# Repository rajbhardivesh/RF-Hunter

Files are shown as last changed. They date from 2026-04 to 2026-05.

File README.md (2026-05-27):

# RF Hunter — Wireless Security Research Platform

**ESP8266 + nRF24L01 · OLED Display · Open Source Hardware & Firmware**


[]()
[]()

> A compact, standalone wireless security research device. Three tools in one — RF jammer, Wi-Fi deauther, and captive portal testbed — controlled from a 128×64 OLED display and 6-button keypad. No laptop required.

---

## Buy a pre-built unit

If you want to skip the build and get straight to learning:

**[→ Buy RF-Hunter at rdhrobotics.in](https://rdhrobotics.in/products/rf-hunter)**

Assembled, tested, and shipped. Includes quick-start card.

---

## What it does

The RF-Hunter is a hardware platform for studying 2.4 GHz wireless security concepts hands-on. It runs three independent research modules from a unified launcher UI:

| Module | Description |
|---|---|
| **RF-Hunter** | Sweeps all 125 nRF24 channels or Wi-Fi bands only. Studies RF interference in the 2.4 GHz space. |
| **Deauther Suite** | spacehuhn deauther engine. Scan APs, study 802.11 management frame behaviour. |
| **WiPhi** | Evil twin AP + captive portal testbed. Study how credential phishing portals work. |
| **RF Chat** | *(bonus sketch)* Point-to-point text chat over raw nRF24 radio. |

Everything is navigated from the OLED + keypad, or remotely via the built-in web admin panel at `192.168.4.1`.

---

## Hardware

| Component | Part |
|---|---|
| MCU | ESP8266 (80/160 MHz, 2.4 GHz Wi-Fi) |
| RF module | nRF24L01+ PA+LNA |
| Display | SH1106 128×64 OLED (I²C) |
| Input | 6-button ADC keypad (voltage divider) |
| Storage | EEPROM — 5-slot credential vault, persists across reboots |

### Pinout

```raw
nRF24L01   CE  → GPIO16
           CSN → GPIO15

SH1106     SDA → GPIO4
           SCL → GPIO5
```

### ADC button thresholds

```cpp
#define BTN_UP     135
#define BTN_DOWN   579
#define BTN_LEFT   426
#define BTN_RIGHT  634
#define BTN_ENTER  729
#define BTN_BACK   687
```

Adjust values to match your resistor network.

---

## Firmware

### Requirements

- Arduino IDE 1.8+ or PlatformIO
- ESP8266 board package
- Libraries: `RF24`, `ESP8266WiFi`, `DNSServer`, `ESP8266WebServer`, `SH1106Wire` (ESP8266-OLED), `ADCButton`, `ArduinoJson v5`

### Install

```bash
git clone https://github.com/rdhrobotics/RF-Hunter.git
```

Open `RFHunter/RFHunter.ino` in Arduino IDE. Select **Generic ESP8266 (Deauther)** as the board. Flash at 115200 baud.

### Repository structure

```raw
RF-Hunter/
├── RFHunter/
│   └── RFHunter.ino        ← main sketch (all three tools)
│
├── Hardware Source/
│   ├── RD_Deauther.pdf // schematic
│   └── RD_Deauther.kicad_pro // Kicad Project

```

---

## UI overview

```raw
┌─────────────────┐
│     Main Menu   │  ← Launcher
│  > RF-Hunter    │
│    Deauther     │
│    WiPhi        │
└─────────────────┘
        │
        ├── RF-Hunter → select mode → running (BACK to stop)
        ├── Deauther  → full spacehuhn DisplayUI
        └── WiPhi     → scan → select AP → attack → captured PW
```

Hold **BACK for 5 seconds** from any mode to return to the launcher main menu.

---

## Adding a new RF mode (3 steps)

The launcher uses a mode table — drop in a new attack without touching the state machine.

**Step 1** — declare your functions:
```cpp
void myMode_init();
void myMode_tick();
```

**Step 2** — add a row to the table:
```cpp
const NrfMode NRF_MODES[] = {
    { "BLE & All 2.4GHz", nrfAttackAllInit,  nrfAttackAllTick,  true },
    { "Just Wi-Fi",       nrfAttackWiFiInit, nrfAttackWiFiTick, true },
    { "My New Mode",      myMode_init,       myMode_tick,       false }, // ← add here
};
```

**Step 3** — write the functions anywhere below. Done.

---

## EEPROM layout

WiPhi saves captured credentials to EEPROM and survives power cycles.

```raw
Addr 0        Magic byte (0xAB) — detects first boot
Addr 1–485    5 slots × (1 valid flag + 32 SSID + 64 PW)

WiPhi vault (in Launcher, offset to avoid deauther collision):
Addr 2000     Magic byte (0xBC)
Addr 2001+    Same slot layout × 5
```

Browse and delete saved passwords from the OLED: **Main Menu → Saved Passwords**.

---

## Web admin panel

While WiPhi is running, connect to:

```raw
SSID:     WiPhi_34732
Password: d347h320
URL:      http://192.168.4.1/admin
```

The web UI and OLED run simultaneously — control from either.

---

## Open source

This project is fully open source — firmware and hardware both.

| | License |
|---|---|
| Firmware | [MIT](LICENSE) |
| Hardware (schematic, BOM) | [CERN OHL v2 Permissive](LICENSE-HW) |

The Deauther Suite module uses the [spacehuhn/esp8266_deauther](https://github.com/SpacehuhnTech/esp8266_deauther) engine, which is also MIT licensed.

Pull requests welcome. See [CONTRIBUTING.md](CONTRIBUTING.md) for guidelines.

---

## Ethical use

This device is built for **authorized security research, CTF competitions, and educational use**.

- Only use on networks and devices you own or have explicit written permission to test
- Unauthorized deauthentication, RF jamming, or credential harvesting is illegal in most jurisdictions
- The authors take no responsibility for misuse

---

## Made with ❤️

by [@rdhrobotics](https://rdhrobotics.in) — open hardware for security education.

**[→ Buy pre-built at rdhrobotics.in](https://rdhrobotics.in/products/rf-hunter)**

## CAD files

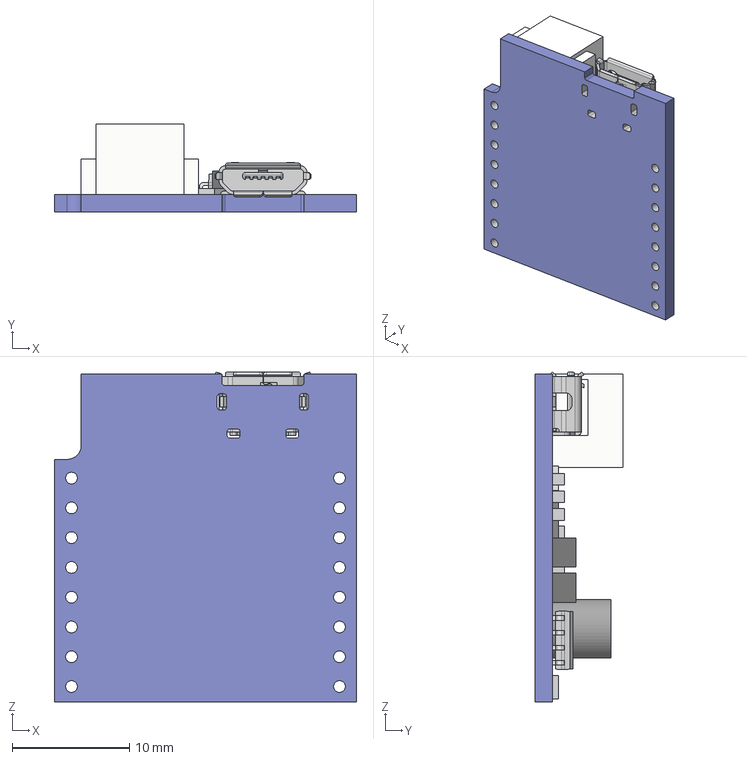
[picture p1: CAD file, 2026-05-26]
Hardware Source/3D/D1_mini_LiPo_Shield.step
25.8 x 7.50 x 28.2 mm

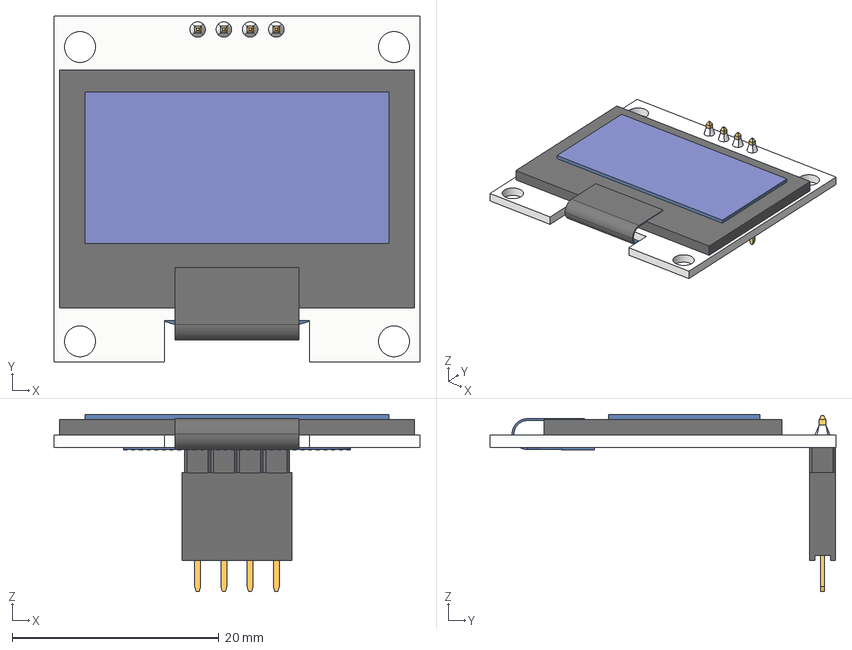
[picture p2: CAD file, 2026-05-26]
Hardware Source/3D/OLED.step
35.4 x 33.5 x 17.1 mm
Board
PIN HEADER MALE 2.54MM P4
LCD
FLEX FILM
4 lü Lehim
PIN HEADER FAMALE 2.54MM P4

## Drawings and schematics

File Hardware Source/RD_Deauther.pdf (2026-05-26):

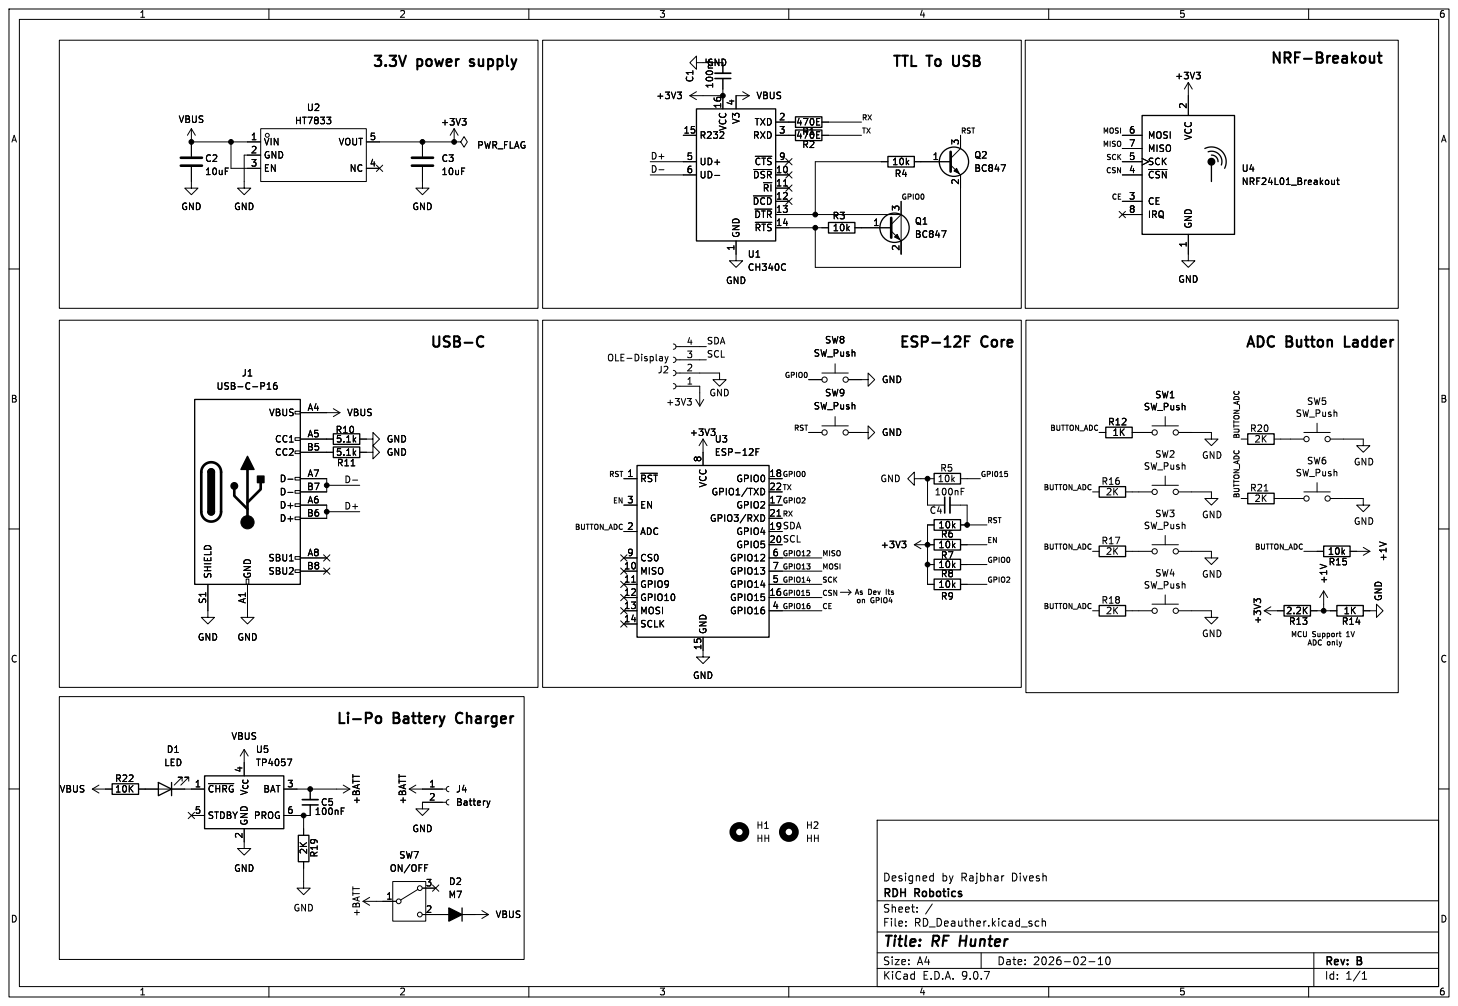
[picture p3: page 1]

1 TXD 2 RXD 3 ~{CTS}9 ~{DSR} 10 ~{RI} 11 ~{DCD} 12 ~{DTR} 13 ~{RTS} 14 U1 CH340C C1 100nF SW2 SW_Push +1V R13

1 TXD 2 RXD 3 ~{CTS}9 ~{DSR} 10 ~{RI} 11 ~{DCD} 12 ~{DTR} 13 ~{RTS} 14 C1 100nF

8 GND 15 GPIO0 18 GPIO1/TXD 22 GPIO2 17 GPIO3/RXD 21 GPIO4 19 GPIO5 20 GPIO12 6 GPIO13 7 GPIO14 5 GPIO15 16 GPIO16 4 GND GND

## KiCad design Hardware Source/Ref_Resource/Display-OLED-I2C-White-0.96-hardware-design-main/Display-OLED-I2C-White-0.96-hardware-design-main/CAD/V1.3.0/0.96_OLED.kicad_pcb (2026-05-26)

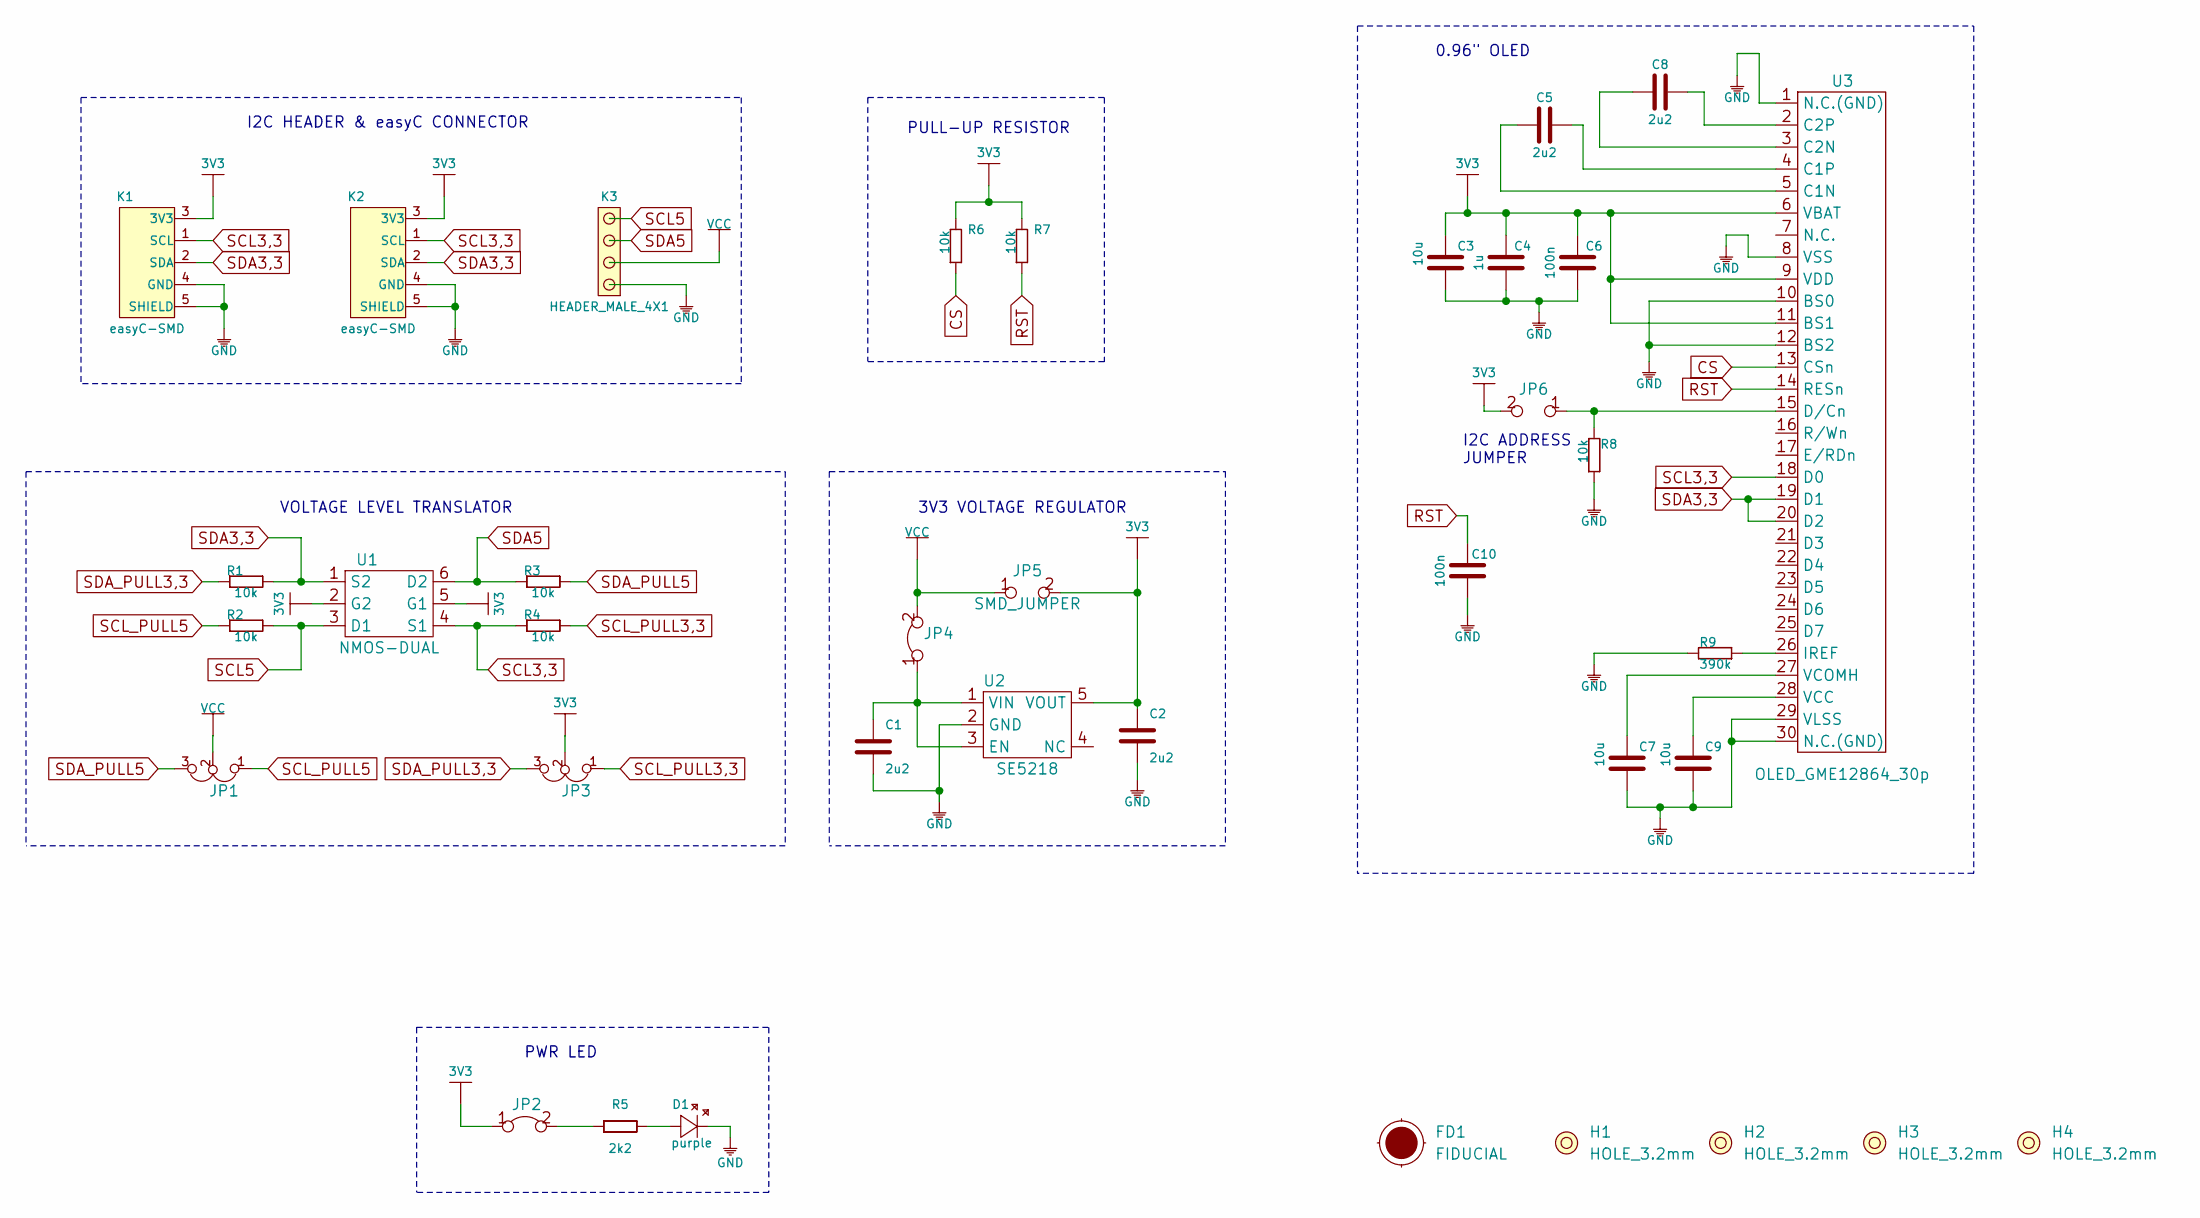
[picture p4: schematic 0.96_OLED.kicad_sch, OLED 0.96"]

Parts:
C1, C2, C5, C8: 2u2; 0603C
C3, C7, C9: 10u; 1206C
C4: 1u; 0603C
C6, C10: 100n; 0603C
D1: purple; 0402LED
FD1: FIDUCIAL; FIDUCIAL_23
H1, H2, H3, H4: HOLE_3.2mm
JP1, JP3: SMD_JUMPER_3_PAD_TRACE
JP2, JP4: SMD-JUMPER-CONNECTED_TRACE_SLODERMASK
JP5, JP6: SMD_JUMPER
K1, K2: easyC-SMD; easyC-connector
K3: HEADER_MALE_4X1
R1, R2, R3, R4, R6, R7, R8: 10k; 0603R
R5: 2k2; 0402R
R9: 390k; 0603R
U1: NMOS-DUAL; SOT-363
U2: SE5218; SOT-23-5
U3: OLED_GME12864_30p; OLED_GME128x64_30p

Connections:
3V3: C2.2, C3.1, C4.1, C6.1, JP2.1, JP3.2, JP5.2, JP6.2, K1.3 (3V3), K2.3 (3V3), R6.2, R7.2, U1.2 (G2), U1.5 (G1), U2.5 (VOUT), U3.6 (VBAT), U3.9 (VDD), U3.11 (BS1)
CS: R6.1, U3.13 (CSn)
GND: C1.1, C2.1, C3.2, C4.2, C6.2, C7.2, C9.2, C10.2, D1.2 (K), K1.4 (GND), K1.5 (SHIELD), K2.4 (GND), K2.5 (SHIELD), K3.1, R8.1, R9.2, U2.2 (GND), U3.1 (N.C.(GND)), U3.8 (VSS), U3.10 (BS0), U3.12 (BS2), U3.29 (VLSS), U3.30 (N.C.(GND))
unnamed: C1.2, JP4.1, U2.1 (VIN), U2.3 (EN)
unnamed: C5.1, U3.5 (C1N)
unnamed: C5.2, U3.4 (C1P)
unnamed: C7.1, U3.27 (VCOMH)
unnamed: C8.1, U3.3 (C2N)
unnamed: C8.2, U3.2 (C2P)
unnamed: C9.1, U3.28 (VCC)
unnamed: D1.1 (A), R5.2
unnamed: JP2.2, R5.1
unnamed: JP6.1, R8.2, U3.15 (D/Cn)
unnamed: R9.1, U3.26 (IREF)
RST: C10.1, R7.1, U3.14 (RESn)
SCL3,3: K1.1 (SCL), K2.1 (SCL), R4.1, U1.4 (S1), U3.18 (D0)
SCL5: K3.4, R2.2, U1.3 (D1)
SCL_PULL3,3: JP3.1, R4.2
SCL_PULL5: JP1.1, R2.1
SDA3,3: K1.2 (SDA), K2.2 (SDA), R1.2, U1.1 (S2), U3.19 (D1), U3.20 (D2)
SDA5: K3.3, R3.1, U1.6 (D2)
SDA_PULL3,3: JP3.3, R1.1
SDA_PULL5: JP1.3, R3.2
VCC: JP1.2, JP4.2, JP5.1, K3.2

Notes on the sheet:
0.96" OLED
3V3 VOLTAGE REGULATOR
I2C ADDRESS JUMPER
I2C HEADER & easyC CONNECTOR
PULL-UP RESISTOR
VOLTAGE LEVEL TRANSLATOR
PWR LED

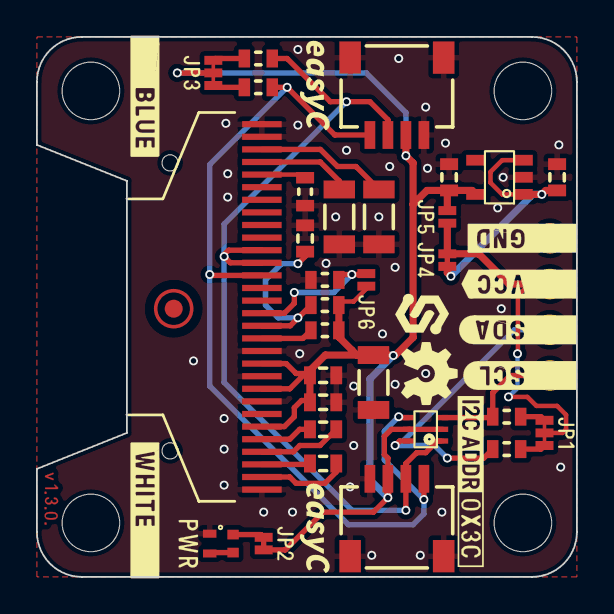
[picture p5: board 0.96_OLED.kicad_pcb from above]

Board: 2 copper layers, 30.0 x 30.0 mm, 37 parts (0 on the bottom side), 24 nets.

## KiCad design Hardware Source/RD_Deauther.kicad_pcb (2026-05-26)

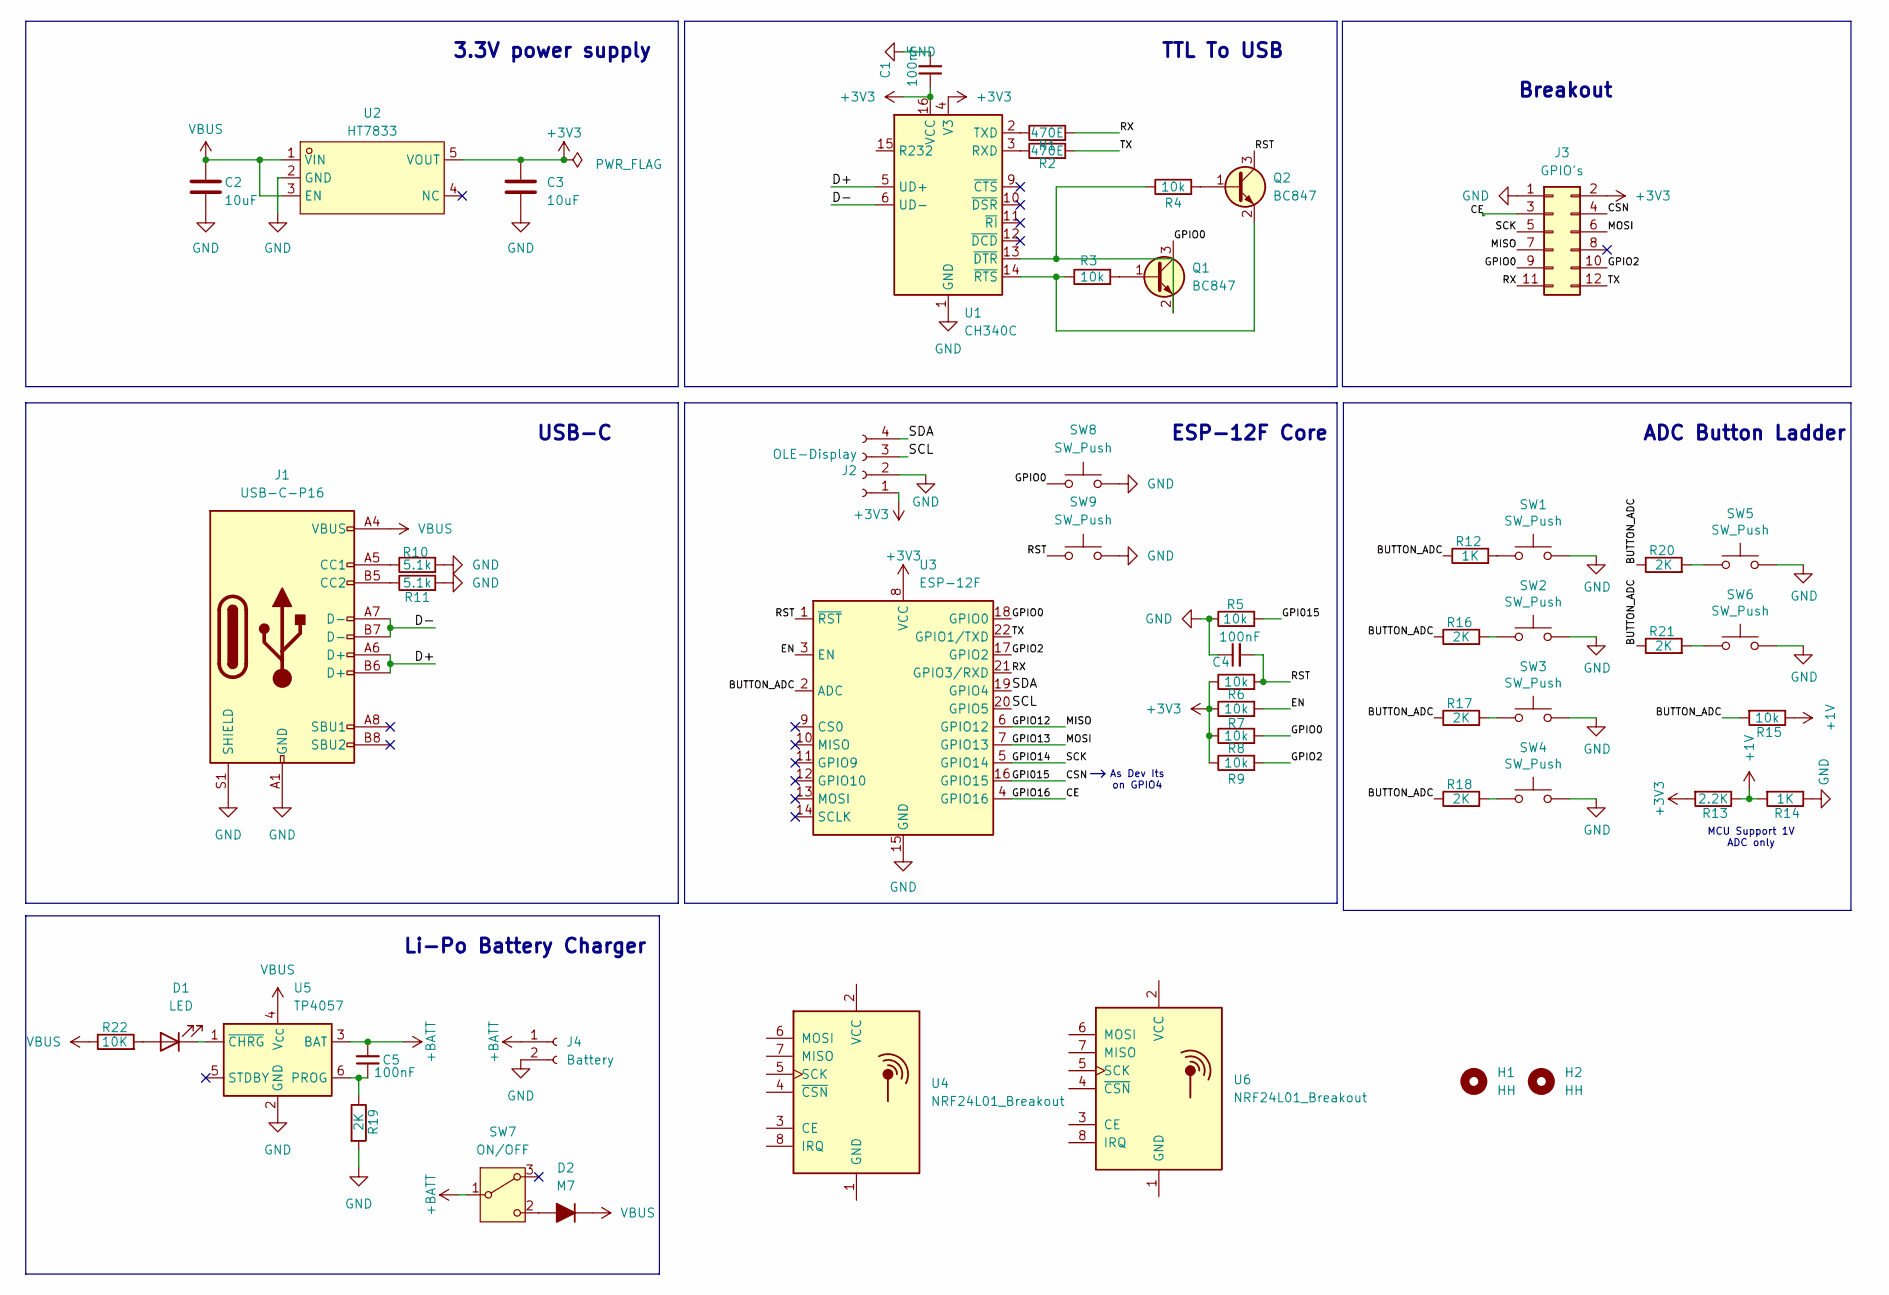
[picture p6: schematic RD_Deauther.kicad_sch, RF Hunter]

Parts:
C1, C4, C5: 100nF; C_1206_3216Metric_Pad1.33x1.80mm_HandSolder
C2, C3: 10uF; C_1206_3216Metric_Pad1.33x1.80mm_HandSolder
D1: LED; LED_1206_3216Metric_Pad1.42x1.75mm_HandSolder
D2: M7; D_SMA
H1, H2: HH; MountingHole_3.2mm_M3
J1: USB-C-P16; USB_C_Receptacle_GCT_USB4105-xx-A_16P_TopMnt_Horizontal
J2: OLE-Display; OLED-1.3Inch
J3: GPIO's; PinSocket_2x06_P2.54mm_Vertical
J4: Battery; JST_PH_B2B-PH-K_1x02_P2.00mm_Vertical
Q1, Q2: BC847; SOT-23
R1, R2: 470E; R_1206_3216Metric_Pad1.30x1.75mm
R3, R4, R5, R6, R7, R8, R9, R15: 10k; R_1206_3216Metric_Pad1.30x1.75mm
R10, R11: 5.1k; R_1206_3216Metric_Pad1.30x1.75mm
R12, R14: 1K; R_1206_3216Metric_Pad1.30x1.75mm
R13: 2.2K; R_1206_3216Metric_Pad1.30x1.75mm
R16, R17, R18, R19, R20, R21: 2K; R_1206_3216Metric_Pad1.30x1.75mm
R22: 10K; R_1206_3216Metric_Pad1.30x1.75mm
SW1, SW2, SW3, SW4, SW5, SW6: SW_Push; SW_Push_1P1T_NO_E-Switch_TL3301NxxxxxG
SW7: ON/OFF; SW_SPDT_PCM12
SW8, SW9: SW_Push; SW_SPST_TL3342
U1: CH340C; SOIC-16_3.9x9.9mm_P1.27mm
U2: HT7833; SOT-23-5; MPN C82942
U3: ESP-12F; ESP-12E
U4, U6: NRF24L01_Breakout; nRF24L01_Breakout
U5: TP4057; TSOT-23-6

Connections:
+1V: R13.1, R14.2, R15.1
+3V3: C1.1, C3.1, J2.1, J3.2, R6.1, R7.1, R8.1, R9.1, R13.2, U1.4 (V3), U1.16 (VCC), U2.5 (VOUT), U3.8 (VCC)
+BATT: C5.2, J4.1, SW7.1 (B), U5.3 (BAT)
/BUTTON_ADC: R12.1, R15.2, R16.1, R17.1, R18.1, R20.1, R21.1, U3.2 (ADC)
/CE: J3.3, U3.4 (GPIO16)
/CSN: J3.4, R5.2, U3.16 (GPIO15)
/D+: J1.A6 (D+), J1.B6 (D+), U1.5 (UD+)
/D-: J1.A7 (D-), J1.B7 (D-), U1.6 (UD-)
/EN: R7.2, U3.3 (EN)
/GPIO0: J3.9, Q1.3 (C), R8.2, SW8.1, U3.18 (GPIO0)
/GPIO2: J3.10, R9.2, U3.17 (GPIO2)
/GPIO12: J3.7, U3.6 (GPIO12)
/GPIO13: J3.6, U3.7 (GPIO13)
/GPIO14: J3.5, U3.5 (GPIO14)
/RST: C4.2, Q2.3 (C), R6.2, SW9.1, U3.1 (~RST)
/RX: J3.11, R1.2, U3.21 (GPIO3/RXD)
/SCL: J2.3, U3.20 (GPIO5)
/SDA: J2.4, U3.19 (GPIO4)
/TX: J3.12, R2.2, U3.22 (GPIO1/TXD)
GND: C1.2, C2.1, C3.2, C4.1, J1.A1 (GND), J1.A12 (GND), J1.B1 (GND), J1.B12 (GND), J1.S1 (SHIELD), J2.2, J3.1, J4.2, R5.1, R10.2, R11.2, R14.1, R19.2, SW1.2, SW2.2, SW3.2, SW4.2, SW5.2, SW6.2, SW8.2, SW9.2, U1.1 (GND), U2.2 (GND), U3.15 (GND), U5.2 (GND)
unnamed: D1.2 (A), R22.2
unnamed: D1.1 (K), U5.1 (~CHRG)
unnamed: D2.2 (A), SW7.2 (C)
unnamed: J1.A5 (CC1), R10.1
unnamed: J1.B5 (CC2), R11.1
unnamed: Q1.1 (B), R3.2
unnamed: Q1.2 (E), R4.1, U1.13 (~DTR)
unnamed: Q2.1 (B), R4.2
unnamed: Q2.2 (E), R3.1, U1.14 (~RTS)
unnamed: R12.2, SW1.1
unnamed: R16.2, SW2.1
unnamed: R17.2, SW3.1
unnamed: R18.2, SW4.1
unnamed: R20.2, SW5.1
unnamed: R21.2, SW6.1
unnamed: R2.1, U1.3 (RXD)
unnamed: R1.1, U1.2 (TXD)
unnamed: C5.1, R19.1, U5.6 (PROG)
VBUS: C2.2, D2.1 (K), J1.A4 (VBUS), J1.A9 (VBUS), J1.B4 (VBUS), J1.B9 (VBUS), R22.1, U2.1 (VIN), U2.3 (EN), U5.4 (V_{CC})

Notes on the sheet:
As Dev Its on GPIO4
MCU Support 1V ADC only
USB-C
Breakout
TTL To USB
Li-Po Battery Charger
3.3V power supply
ESP-12F Core
ADC Button Ladder

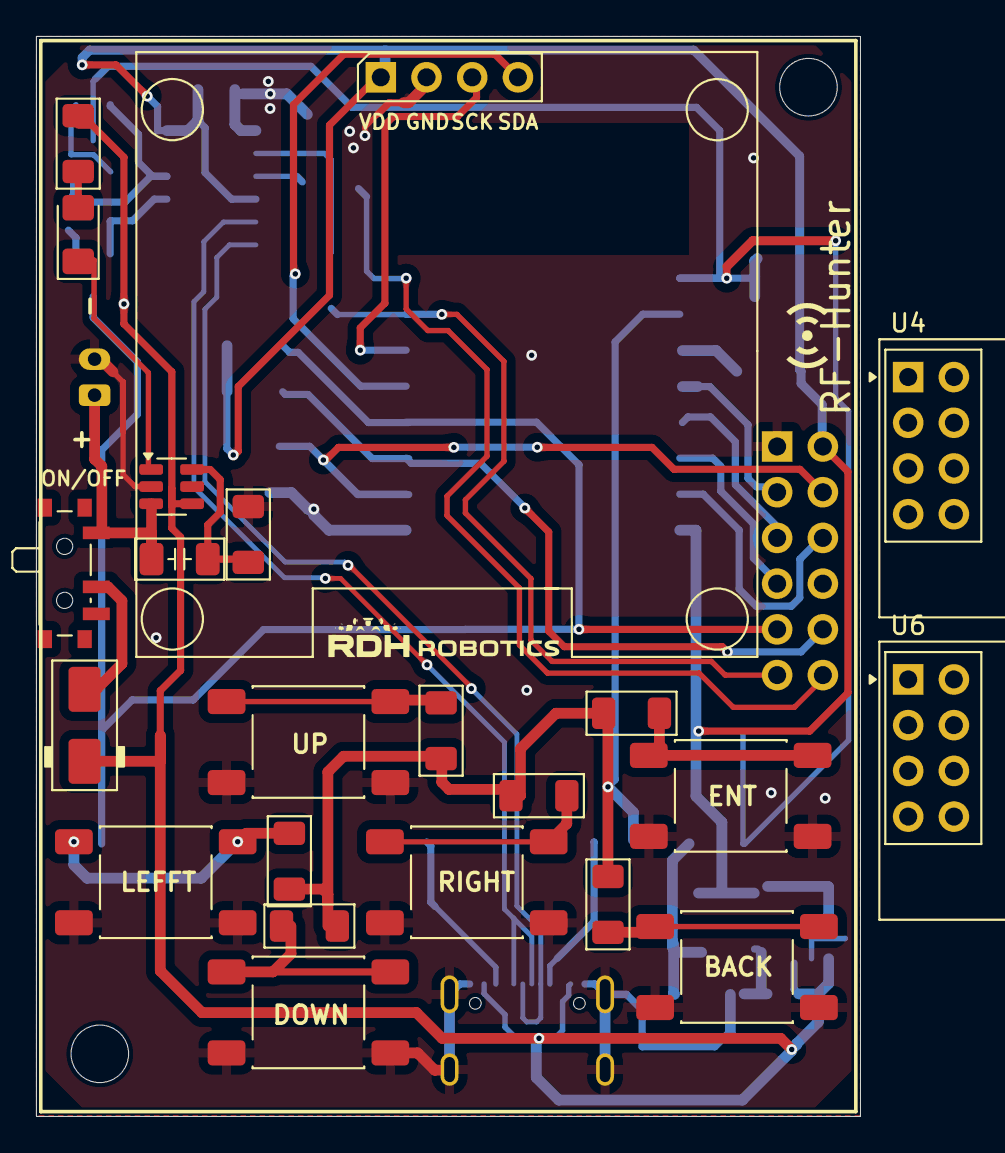
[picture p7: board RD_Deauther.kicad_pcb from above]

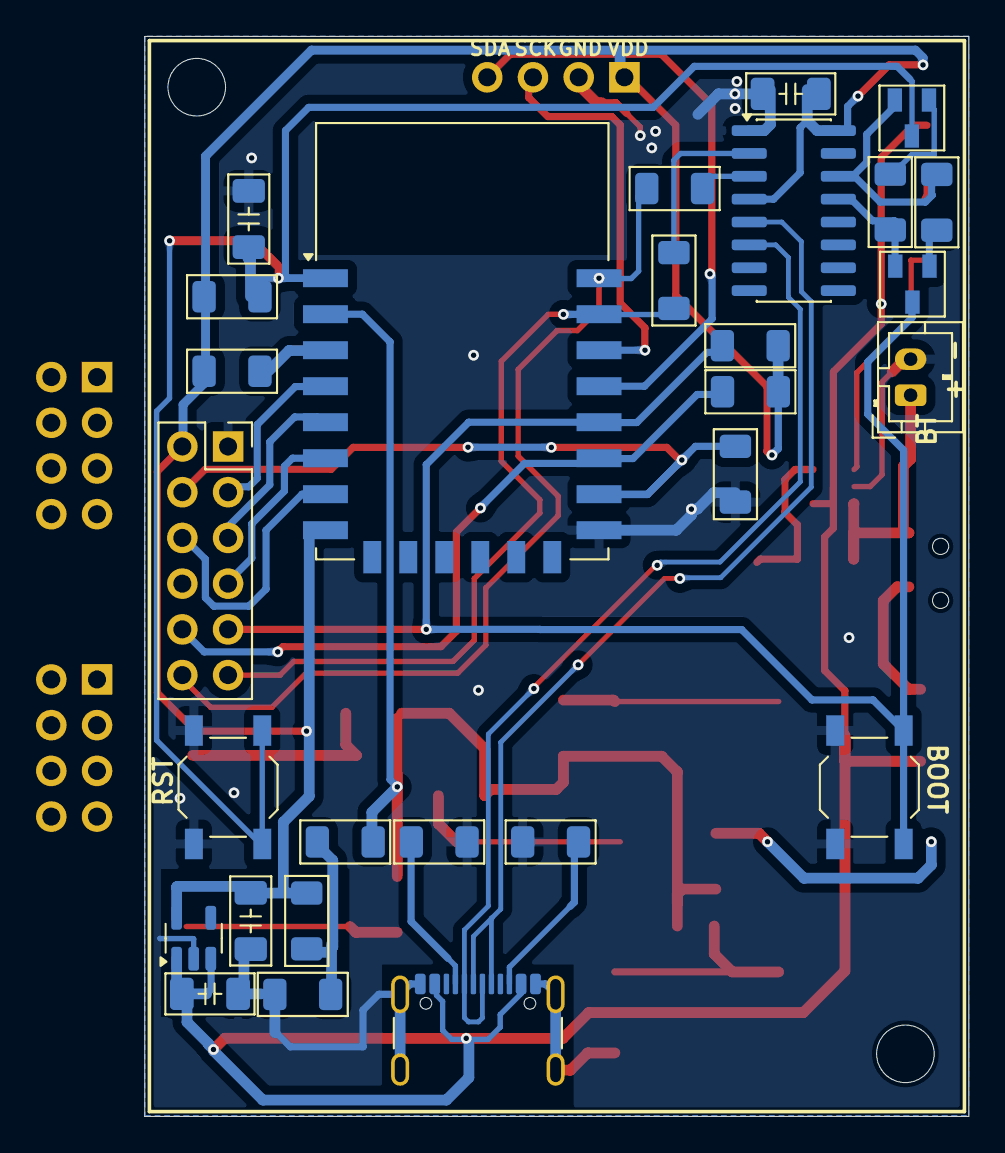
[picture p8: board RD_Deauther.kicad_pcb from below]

Board: 2 copper layers, 45.8 x 60.0 mm, 52 parts (28 on the bottom side), 39 nets.

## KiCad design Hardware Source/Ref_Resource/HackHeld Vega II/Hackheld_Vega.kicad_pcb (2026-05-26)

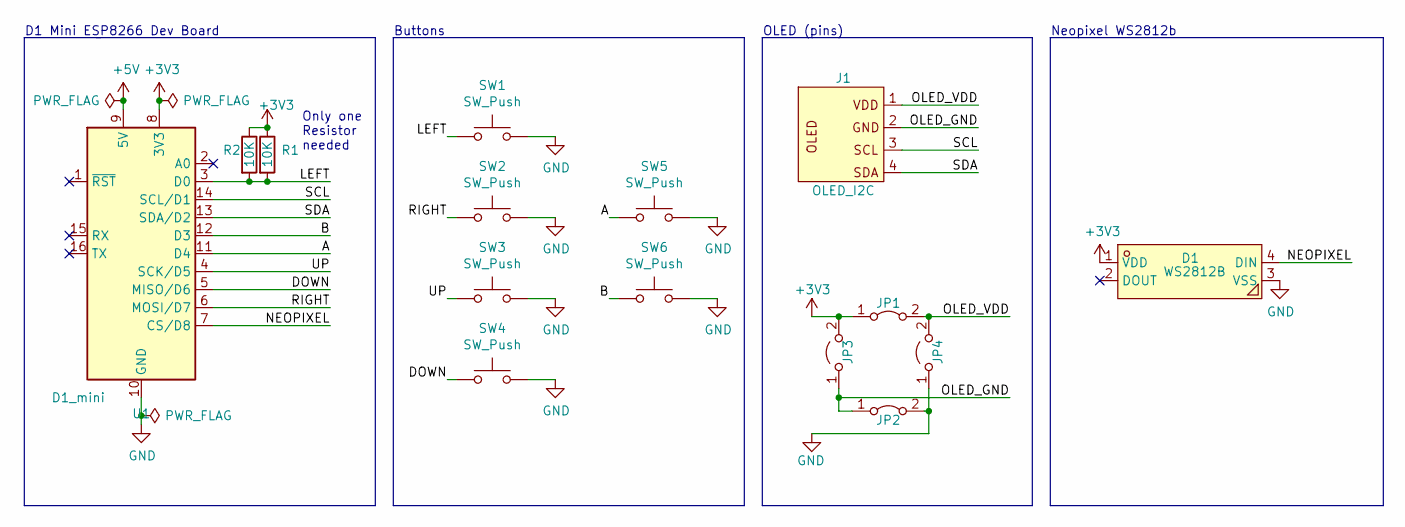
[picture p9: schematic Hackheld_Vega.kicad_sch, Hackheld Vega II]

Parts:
D1: WS2812B; LED-SMD_4P-L5.0-W5.0-BL_TC5050RGB-handsolder; MPN C114586
J1: OLED_I2C; OLED_I2C_1.3
JP1, JP2: Jumper_2_Bridged; Bridge
JP3, JP4: Jumper_2_Open; SolderJumper_Open
R1: 10K; R_1206_3216Metric_Pad1.30x1.75mm_HandSolder
R2: 10K; R_Axial_DIN0204_L3.6mm_D1.6mm_P7.62mm_Horizontal
SW1, SW2, SW3, SW4, SW6: SW_Push; SW-KEY-TH_4P-L6.0-W6.0-P4.50-LS6.5; MPN C381013; LCSC Part C381013
SW5: SW_Push; SW-KEY-TH_4P-L6.0-W6.0-P4.50-LS6.5; MPN C381013
U1: D1_mini; D1_mini_ESP8266

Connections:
+3V3: D1.1 (VDD), JP1.1 (A), JP3.2 (B), R1.1, R2.1, U1.8 (3V3)
+5V: U1.9 (5V)
/A: SW5.1 (A), U1.11 (D4)
/B: SW6.1 (A), U1.12 (D3)
/DOWN: SW4.1 (A), U1.5 (MISO/D6)
/LEFT: R1.2, R2.2, SW1.1 (A), U1.3 (D0)
/NEOPIXEL: D1.4 (DIN), U1.7 (CS/D8)
/OLED_GND: J1.2 (GND), JP2.1 (A), JP3.1 (A)
/OLED_VDD: J1.1 (VDD), JP1.2 (B), JP4.2 (B)
/RIGHT: SW2.1 (A), U1.6 (MOSI/D7)
/SCL: J1.3 (SCL), U1.14 (SCL/D1)
/SDA: J1.4 (SDA), U1.13 (SDA/D2)
/UP: SW3.1 (A), U1.4 (SCK/D5)
GND: D1.3 (VSS), JP2.2 (B), JP4.1 (A), SW1.2 (B), SW2.2 (B), SW3.2 (B), SW4.2 (B), SW5.2 (B), SW6.2 (B), U1.10 (GND)

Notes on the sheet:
OLED (pins)
D1 Mini ESP8266 Dev Board
Neopixel WS2812b
Buttons
Only one Resistor needed

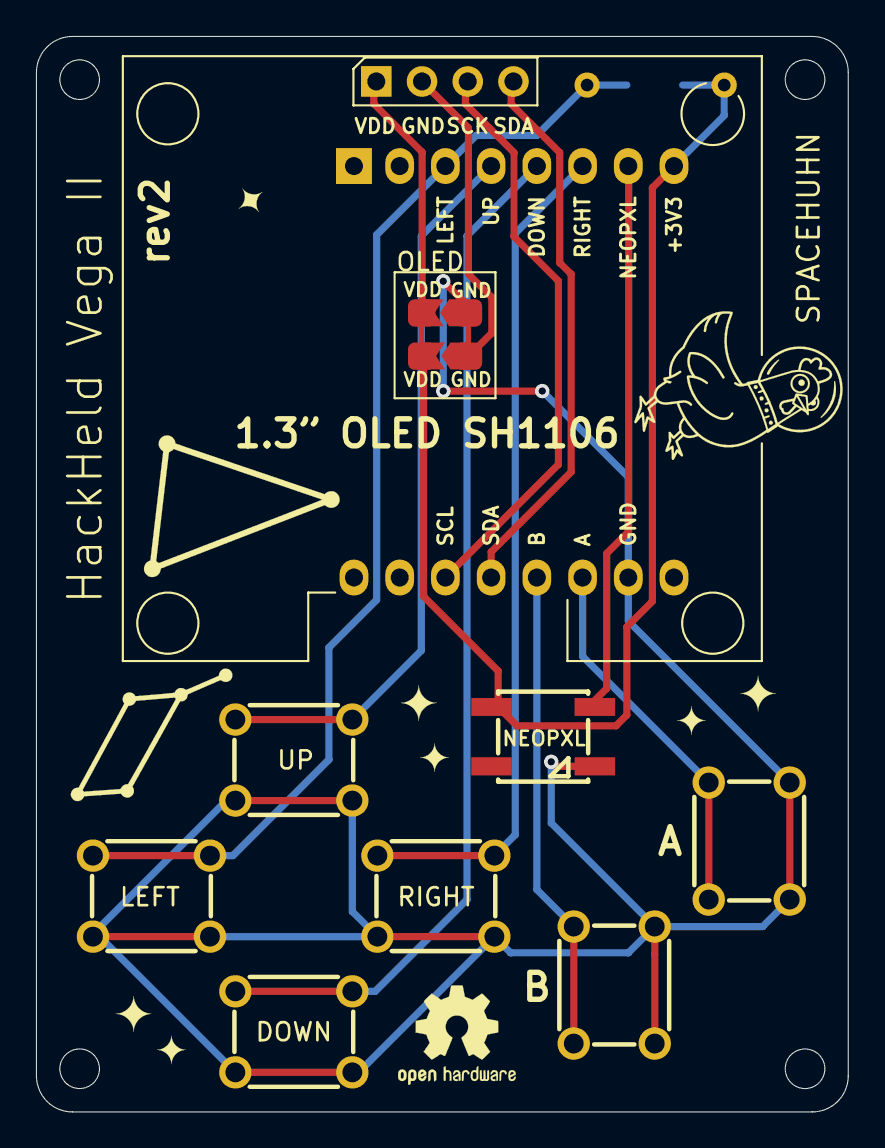
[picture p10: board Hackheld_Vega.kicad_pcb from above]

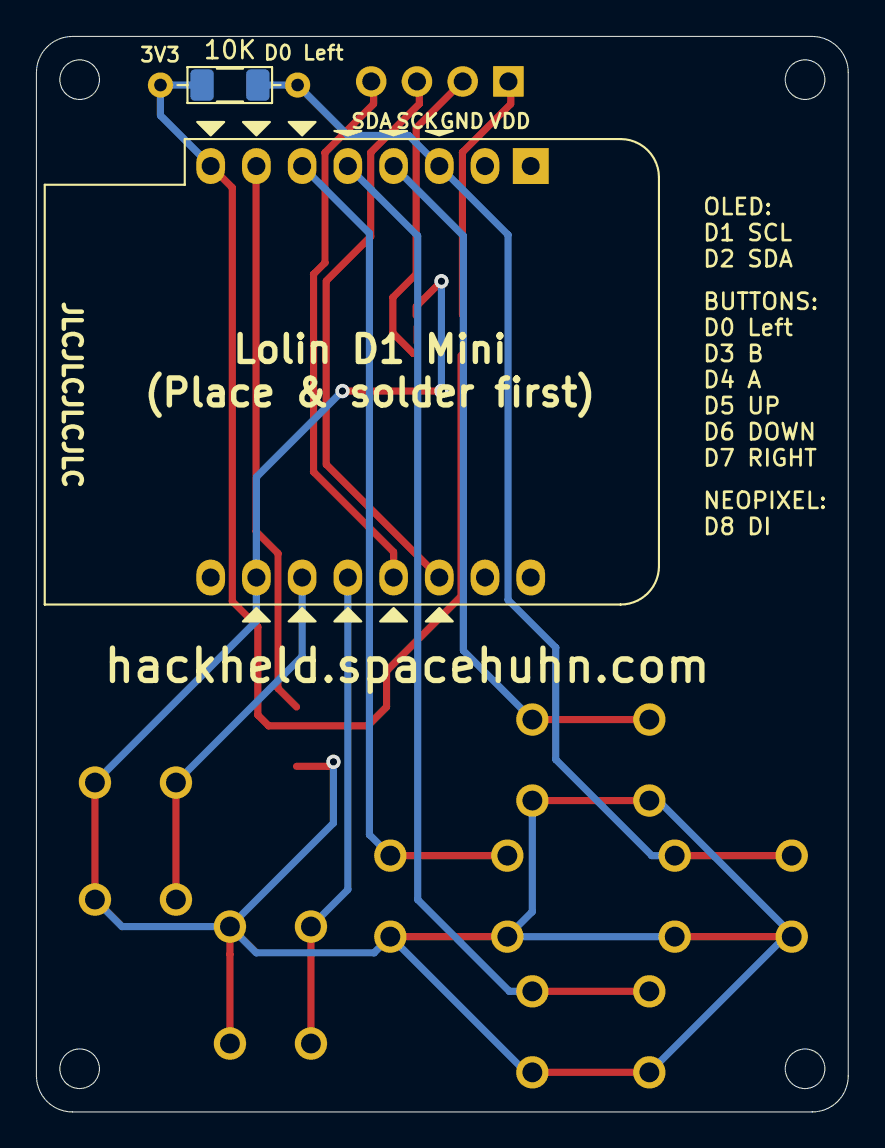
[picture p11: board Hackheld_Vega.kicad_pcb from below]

Board: 2 copper layers, 45.1 x 59.8 mm, 30 parts (3 on the bottom side), 13 nets.

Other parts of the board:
G3, G5, G7, G13: LOGO; star_tiny
G4, G6, G8: LOGO; star_small
G9: LOGO; lyra
G10: LOGO; summer_triangle
G11: OSHW-Logo2_7.3x6mm_SilkScreen
G14: LOGO; spacehuhn
REF1, REF2, REF3, REF4: MountingHole_2.2mm_M2

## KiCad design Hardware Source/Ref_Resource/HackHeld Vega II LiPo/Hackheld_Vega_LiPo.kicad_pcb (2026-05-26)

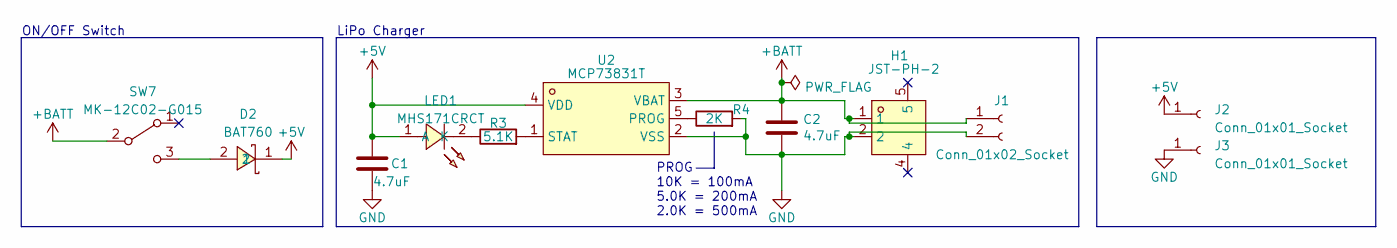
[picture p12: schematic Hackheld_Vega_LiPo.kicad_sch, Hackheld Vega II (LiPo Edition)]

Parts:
C1, C2: 4.7uF; C_0603_1608Metric
D2: BAT760; SOD-323_L1.8-W1.3-LS2.5-RD; MPN C116158
H1: JST-PH-2; CONN-SMD_2P-P2.00_XUNPU_WAFER-PH2.0-2PWB; MPN C3029440
J1: Conn_01x02_Socket; PinSocket_1x02_P2.54mm_Vertical
J2, J3: Conn_01x01_Socket; PinSocket_1x01_P2.54mm_Vertical
LED1: MHS171CRCT; LED-SMD_L2.0-W1.1_SIDE; MPN C693903
R3: 5.1K; R_0402_1005Metric
R4: 2K; R_0402_1005Metric
SW7: MK-12C02-G015; SW_MK-12C02-G020; MPN C2911519
U2: MCP73831T; SOT-23-5_L3.0-W1.7-P0.95-LS2.8-BL; MPN C424093

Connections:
+5V: C1.1, D2.1, J2.1, LED1.1 (A), U2.4 (VDD)
+BATT: C2.1, H1.1, J1.1, SW7.2 (B), U2.3 (VBAT)
GND: C1.2, C2.2, H1.2, J1.2, J3.1, R4.2, U2.2 (VSS)
unnamed: LED1.2 (K), R3.1
unnamed: D2.2, SW7.3 (C)
unnamed: R4.1, U2.5 (PROG)
unnamed: R3.2, U2.1 (STAT)

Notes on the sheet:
LiPo Charger
ON/OFF Switch
PROG 10K = 100mA 5.0K = 200mA 2.0K = 500mA

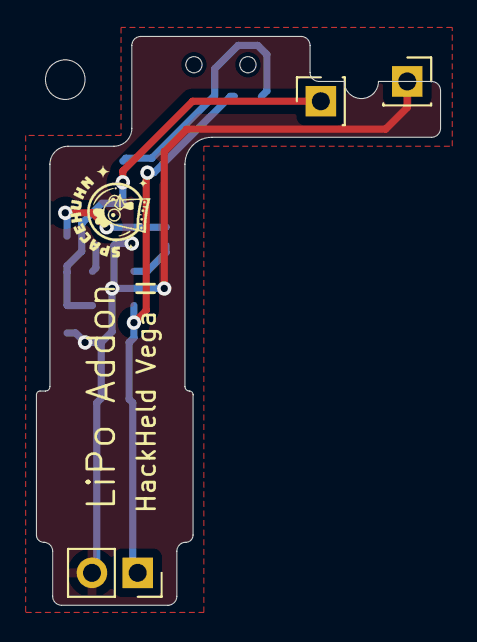
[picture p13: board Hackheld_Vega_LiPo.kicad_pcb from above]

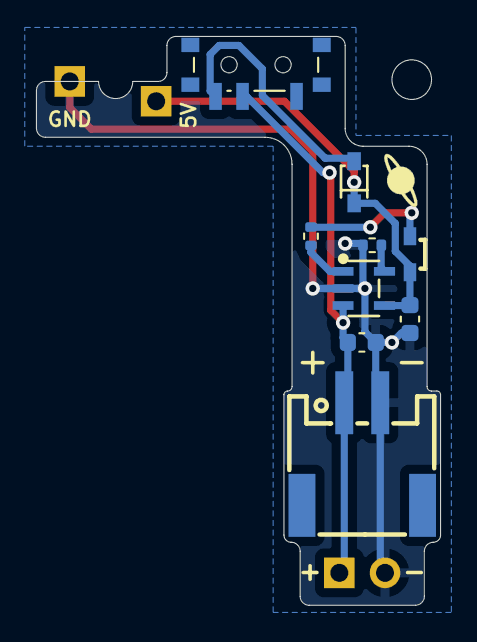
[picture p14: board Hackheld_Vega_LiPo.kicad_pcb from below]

Board: 2 copper layers, 22.4 x 31.6 mm, 16 parts (9 on the bottom side), 7 nets.

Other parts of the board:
REF1, REF2, REF3, REF4: MountingHole_2.2mm_M2

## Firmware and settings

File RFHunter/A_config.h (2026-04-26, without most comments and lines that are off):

#pragma once
#define ENABLE_DEBUG
#define DEBUG_PORT Serial
#define DEBUG_BAUD 115200
 #define HACKHELD_VEGA
  #define USE_DISPLAY true
  #define FLIP_DIPLAY true
  #define SH1106_I2C
  #define I2C_ADDR 0x3C
  #define I2C_SDA 4      // D2
  #define I2C_SCL 5      // D1
#define BTN_UP    135
#define BTN_DOWN  579
#define BTN_LEFT  426
#define BTN_RIGHT 634
#define BTN_ENTER 729
#define BTN_BACK  687
#define BTN_TOLERANCE 8
  #define AUTOSAVE_ENABLED true
  #define AUTOSAVE_TIME 60
  #define ATTACK_ALL_CH false
  #define RANDOM_TX false
  #define ATTACK_TIMEOUT 600
  #define DEAUTHS_PER_TARGET 25
  #define DEAUTH_REASON 1
  #define BEACON_INTERVAL_100MS true
  #define PROBE_FRAMES_PER_SSID 1
  #define CH_TIME 200
  #define MIN_DEAUTH_FRAMES 3
  #define AP_SSID "pwned"
  #define AP_PASSWD "deauther"
  #define AP_HIDDEN false
  #define AP_IP_ADDR { 192, 168, 4, 1 }
  #define WEB_ENABLED true
  #define WEB_CAPTIVE_PORTAL false
  #define WEB_USE_SPIFFS false
  #define DEFAULT_LANG "en"
  #define CLI_ENABLED true
  #define CLI_ECHO true
#if !defined(LED_DIGITAL) && !defined(LED_RGB) && !defined(LED_NEOPIXEL) && !defined(LED_MY92) && !defined(LED_DOTSTAR)
  #define LED_DIGITAL
  #define USE_LED false
#else // if !defined(LED_DIGITAL) && !defined(LED_RGB) && !defined(LED_NEOPIXEL) && !defined(LED_MY92) && !defined(LED_DOTSTAR)
  #define USE_LED true
#endif // if !defined(LED_DIGITAL) && !defined(LED_RGB) && !defined(LED_NEOPIXEL) && !defined(LED_MY92) && !defined(LED_DOTSTAR)
  #define LED_PIN_R 255
  #define LED_PIN_G 255
  #define LED_PIN_B 255
  #define LED_ANODE false
  #define LED_MODE_OFF 0, 0, 0
  #define LED_MODE_SCAN 0, 0, 255
  #define LED_MODE_ATTACK 255, 0, 0
  #define LED_MODE_IDLE 0, 255, 0
  #define LED_MODE_BRIGHTNESS 10
  #define DISPLAY_TIMEOUT 600
  #define DISPLAY_TEXT ""
#if !defined(SSD1306_I2C) && !defined(SSD1306_SPI) && !defined(SH1106_I2C) && !defined(SH1106_SPI)
  #define SSD1306_I2C
  #define USE_DISPLAY false
#else
  #define USE_DISPLAY true
#endif
  #define SPI_RES 5
  #define SPI_DC 4
  #define SPI_CS 15
  #define BUTTON_UP 255
  #define BUTTON_DOWN 255
  #define BUTTON_A 255
  #define BUTTON_B 255
  #if BUTTON_UP != 0 && BUTTON_DOWN != 0 && BUTTON_A != 0 && BUTTON_B != 0
    #define RESET_BUTTON 0
  #else // if BUTTON_UP != 0 && BUTTON_DOWN != 0 && BUTTON_A != 0 && BUTTON_B != 0
    #define RESET_BUTTON 255
  #endif // if BUTTON_UP != 0 && BUTTON_DOWN != 0 && BUTTON_A != 0 && BUTTON_B != 0
  #define WEB_IP_ADDR (192, 168, 4, 1)
  #define WEB_URL "deauth.me"
#define DEAUTHER_VERSION "1.0"
#define DEAUTHER_VERSION_MAJOR 2
#define DEAUTHER_VERSION_MINOR 6
#define DEAUTHER_VERSION_REVISION 1
#define EEPROM_SIZE 4095
#define BOOT_COUNTER_ADDR 1
#define SETTINGS_ADDR 100
#if LED_MODE_BRIGHTNESS == 0
#error LED_MODE_BRIGHTNESS must not be zero!
#endif

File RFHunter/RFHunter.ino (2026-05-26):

/* =====================
   This software is licensed under the MIT License:
   https://github.com/spacehuhntech/esp8266_deauther
   ===================== */

extern "C" {
  #include "user_interface.h"
}

#include <SPI.h>
#include <Wire.h>
#include <Adafruit_GFX.h>
#include <Adafruit_SH110X.h>
#include <RF24.h>
#ifdef printf_P
#undef printf_P
#endif
#include <DNSServer.h>
#include <ESP8266WebServer.h>
#include <EEPROM.h>

#include "EEPROMHelper.h"

#include "src/ArduinoJson-v5.13.5/ArduinoJson.h"
#if ARDUINOJSON_VERSION_MAJOR != 5
#error Please upgrade/downgrade ArduinoJSON library to version 5!
#endif

#include "oui.h"
#include "language.h"
#include "functions.h"
#include "settings.h"
#include "Names.h"
#include "SSIDs.h"
#include "Scan.h"
#include "Attack.h"
#include "CLI.h"
#include "DisplayUI.h"
#include "A_config.h"

#define PIN_CE  16
#define PIN_CSN 15

// ============================================================
//  WiPhi EEPROM layout
//  Use a high offset to avoid clashing with deauther EEPROM area
// ============================================================
#define WIPHI_EE_BASE      2048
#define WIPHI_EE_MAGIC     0xAB
#define WIPHI_EE_MAGIC_ADDR (WIPHI_EE_BASE + 0)
#define WIPHI_EE_SLOTS     5
#define WIPHI_EE_SSID_LEN  32
#define WIPHI_EE_PW_LEN    64
#define WIPHI_EE_SLOT_SIZE (WIPHI_EE_SSID_LEN + WIPHI_EE_PW_LEN + 1)
#define WIPHI_EE_DATA_START (WIPHI_EE_BASE + 1)
#define WIPHI_EE_TOTAL     (1 + WIPHI_EE_SLOTS * WIPHI_EE_SLOT_SIZE + 4)

struct SavedPW {
    bool   valid;
    char   ssid[WIPHI_EE_SSID_LEN];
    char   pw[WIPHI_EE_PW_LEN];
};
Adafruit_SH1106G display = Adafruit_SH1106G(128, 64, &Wire, -1);

// ============================================================
//  WiPhi network struct
// ============================================================
typedef struct {
    String  ssid;
    uint8_t ch;
    uint8_t bssid[6];
    int32_t rssi;
} _Network;

// ============================================================
//  WiPhi UI States
// ============================================================
typedef enum {
    UI_SPLASH = 0,
    UI_MAIN_MENU,
    UI_SCANNING,
    UI_AP_LIST,
    UI_ATTACK_MENU,
    UI_RUNNING,
    UI_CAPTURED,
    UI_PW_LIST,
    UI_PW_DETAIL
} WiPhiUIState;

#define WIPHI_MAIN_ITEMS 5
const char* WIPHI_MAIN_LABELS[WIPHI_MAIN_ITEMS] = {
    "Scan Networks",
    "Select AP",
    "Attack",
    "Captured PW",
    "Saved Passwords"
};

#define WIPHI_ATK_ITEMS 4
const char* WIPHI_ATK_LABELS[WIPHI_ATK_ITEMS] = {
    "Deauth Only",
    "Deauth + EvilTwin",
    "Stop Attack",
    "Back"
};

// ============================================================
//  WiPhi globals
// ============================================================
_Network _wiphi_networks[16];
_Network _wiphi_selectedNetwork;
int      _wiphi_networkCount = 0;

const byte       WIPHI_DNS_PORT = 53;
const IPAddress  wiphi_apIP(192, 168, 4, 1);
DNSServer        wiphi_dnsServer;
ESP8266WebServer wiphi_webServer(80);

String _wiphi_correct     = "";
String _wiphi_tryPassword = "";
bool   wiphi_hotspot_active   = false;
bool   wiphi_deauthing_active = false;

unsigned long _wiphi_deauthNow   = 0;
unsigned long _wiphi_deauthCount = 0;

WiPhiUIState wiphi_ui_state = UI_SPLASH;
int wiphi_menuSel  = 0;
int wiphi_apSel    = 0;
int wiphi_atkSel   = 0;
int wiphi_pwSel    = 0;
bool wiphi_started = false;

// ============================================================
//  Launcher
// ============================================================
struct NrfMode {
    const char* label;
    void (*init)();
    void (*tick)();
    bool needsCarrier;
};

void nrfAttackAllInit();
void nrfAttackAllTick();
void nrfAttackWiFiInit();
void nrfAttackWiFiTick();

enum class AppMode {
    MAIN_MENU,
    NRF_MENU,
    NRF_RUNNING,
    DEAUTHER_SUITE,
    WIPHI_APP
};

// Run-Time Variables //
Names names;
SSIDs ssids;
Accesspoints accesspoints;
Stations     stations;
Scan   scan;
Attack attack;
CLI    cli;
DisplayUI displayUI;
RF24 radio(PIN_CE, PIN_CSN);

#include "wifi.h"

uint32_t autosaveTime = 0;
uint32_t currentTime  = 0;

bool booted = false;
bool deautherStarted = false;
bool nrfReady = false;
bool carrierActive = false;

AppMode appMode = AppMode::MAIN_MENU;
int mainSelected = 0;
int nrfSelected = 0;
int activeNrfMode = -1;

const byte NRF_CARRIER_CH = 45;
const int wifiChannels[] = { 12, 13, 14, 15, 16, 17, 18, 19, 20, 21, 22 };
const int numWifiCh = sizeof(wifiChannels) / sizeof(wifiChannels[0]);

const char* MAIN_MENU_ITEMS[] = {
    "RF-Hunter",
    "Deauther-Suite",
    "WiPhi"
};
const int MAIN_MENU_COUNT = sizeof(MAIN_MENU_ITEMS) / sizeof(MAIN_MENU_ITEMS[0]);

const NrfMode NRF_MODES[] = {
    { "BLE & All 2.4GHz", nrfAttackAllInit,  nrfAttackAllTick,  true },
    { "Just Wi-Fi",       nrfAttackWiFiInit, nrfAttackWiFiTick, true },
};
const int NRF_MODE_COUNT = sizeof(NRF_MODES) / sizeof(NRF_MODES[0]);

void updateButtons();
void drawMainMenu();
void drawNrfMenu();
void drawNrfRunning();
void drawNrfBootScreen();
void drawNrfError();
bool setupNrfRadio();
void startNrfMode(int idx);
void stopNrfMode();
void startCarrier();
void stopCarrier();
void startDeautherSuite();
void startWiPhiApp();
void stopWiPhiApp();
void returnToMainMenu();
void updateMainMenu();
void updateNrfMenu();
void updateNrfRunning();
void updateDeautherSuite();
void updateWiPhiApp();

// WiPhi forward decls
void wiphi_drawSplash();
void wiphi_drawMainMenu();
void wiphi_drawScanningFrame(int p);
void wiphi_drawApList();
void wiphi_drawAttackMenu();
void wiphi_drawRunning();
void wiphi_drawCaptured();
void wiphi_drawPwList();
void wiphi_drawPwDetail(int slot);
void wiphi_titleBar(const char* t);
void wiphi_menuItem(int y, bool sel, const char* label);
void wiphi_performScan();
void wiphi_startDeauth();
void wiphi_stopDeauth();
void wiphi_startEvilTwin();
void wiphi_stopEvilTwin();
void wiphi_tickDeauth();
String wiphi_bytesToStr(const uint8_t* b, uint32_t size);
String wiphi_header(String t);
String wiphi_indexPage();
void   wiphi_handleIndex();
void   wiphi_handleResult();
void   wiphi_handleAdmin();

// ============================================================
//  WiPhi EEPROM helpers
// ============================================================
void wiphi_eeWriteSlot(int slot, const SavedPW& s) {
    int base = WIPHI_EE_DATA_START + slot * WIPHI_EE_SLOT_SIZE;
    EEPROM.write(base, s.valid ? 1 : 0);
    for (int i = 0; i < WIPHI_EE_SSID_LEN; i++) EEPROM.write(base + 1 + i, s.ssid[i]);
    for (int i = 0; i < WIPHI_EE_PW_LEN;   i++) EEPROM.write(base + 1 + WIPHI_EE_SSID_LEN + i, s.pw[i]);
    EEPROM.commit();
}

SavedPW wiphi_eeReadSlot(int slot) {
    SavedPW s;
    int base = WIPHI_EE_DATA_START + slot * WIPHI_EE_SLOT_SIZE;
    s.valid = (EEPROM.read(base) == 1);
    for (int i = 0; i < WIPHI_EE_SSID_LEN; i++) s.ssid[i] = EEPROM.read(base + 1 + i);
    for (int i = 0; i < WIPHI_EE_PW_LEN;   i++) s.pw[i]   = EEPROM.read(base + 1 + WIPHI_EE_SSID_LEN + i);
    s.ssid[WIPHI_EE_SSID_LEN - 1] = 0;
    s.pw[WIPHI_EE_PW_LEN - 1] = 0;
    return s;
}

void wiphi_eeDeleteSlot(int slot) {
    SavedPW empty;
    empty.valid = false;
    memset(empty.ssid, 0, WIPHI_EE_SSID_LEN);
    memset(empty.pw,   0, WIPHI_EE_PW_LEN);
    wiphi_eeWriteSlot(slot, empty);
}

int wiphi_eeSave(const char* ssid, const char* pw) {
    for (int i = 0; i < WIPHI_EE_SLOTS; i++) {
        SavedPW s = wiphi_eeReadSlot(i);
        if (!s.valid) {
            SavedPW n;
            n.valid = true;
            strncpy(n.ssid, ssid, WIPHI_EE_SSID_LEN - 1); n.ssid[WIPHI_EE_SSID_LEN - 1] = 0;
            strncpy(n.pw,   pw,   WIPHI_EE_PW_LEN   - 1); n.pw[WIPHI_EE_PW_LEN   - 1] = 0;
            wiphi_eeWriteSlot(i, n);
            return i;
        }
    }
    return -1;
}

// ============================================================
//  WiPhi display helpers — uses displayUI.display
// ============================================================
static inline void wiphi_setFontSmall() {
    displayUI.display.setFont(ArialMT_Plain_10);
}

void wiphi_titleBar(const char* title) {
    displayUI.display.fillRect(0, 0, 128, 12);
    displayUI.display.setColor(BLACK);
    int xpos = (128 - (int)strlen(title) * 6) / 2;
    if (xpos < 2) xpos = 2;
    displayUI.display.drawString(xpos, 1, title);
    displayUI.display.setColor(WHITE);
}

void wiphi_menuItem(int y, bool sel, const char* label) {
    char row[28];
    snprintf(row, sizeof(row), "%s %s", sel ? ">" : " ", label);
    displayUI.display.drawString(2, y, row);
}

void wiphi_drawSplash() {
    displayUI.display.clear();
    wiphi_setFontSmall();
    displayUI.display.drawString(34,  8, "Booting");
    displayUI.display.drawString(14, 22, "WiPhi Evil");
    displayUI.display.drawString(16, 36, "by @rdhrobotics");
    displayUI.display.display();
}

void wiphi_drawScanningFrame(int progress) {
    displayUI.display.clear();
    wiphi_setFontSmall();
    wiphi_titleBar("Scanning...");
    displayUI.display.drawString(14, 16, "Scanning WiFi...");
    displayUI.display.drawString(30, 30, "Please wait");
    displayUI.display.drawRect(10, 44, 108, 9);
    int fill = (progress * 106) / 100;
    if (fill > 0) displayUI.display.fillRect(11, 45, fill, 7);
    displayUI.display.display();
}

void wiphi_drawMainMenu() {
    displayUI.display.clear();
    wiphi_setFontSmall();
    wiphi_titleBar("WiPhi");

    if (_wiphi_selectedNetwork.ssid != "") {
        displayUI.display.setColor(BLACK);
        String tag = _wiphi_selectedNetwork.ssid.substring(0, 8);
        displayUI.display.drawString(128 - (int)tag.length() * 6 - 2, 1, tag.c_str());
        displayUI.display.setColor(WHITE);
    }

    int visStart = 0;
    if (wiphi_menuSel >= 4) visStart = wiphi_menuSel - 3;

    for (int i = 0; i < 4; i++) {
        int idx = visStart + i;
        if (idx >= WIPHI_MAIN_ITEMS) break;
        wiphi_menuItem(13 + i * 13, idx == wiphi_menuSel, WIPHI_MAIN_LABELS[idx]);
    }

    if (visStart > 0)                       displayUI.display.drawString(122, 13, "^");
    if (visStart + 4 < WIPHI_MAIN_ITEMS)    displayUI.display.drawString(122, 52, "v");

    displayUI.display.display();
}

void wiphi_drawApList() {
    displayUI.display.clear();
    wiphi_setFontSmall();
    wiphi_titleBar("Select AP");

    if (_wiphi_networkCount == 0) {
        displayUI.display.drawString(8, 20, "No networks found.");
        displayUI.display.drawString(8, 34, "Scan first.");
        displayUI.display.display();
        return;
    }

    int visStart = 0;
    if (wiphi_apSel >= 4) visStart = wiphi_apSel - 3;

    for (int i = 0; i < 4; i++) {
        int idx = visStart + i;
        if (idx >= _wiphi_networkCount) break;
        int y   = 13 + i * 13;
        bool sel = (idx == wiphi_apSel);

        String ssid = _wiphi_networks[idx].ssid;
        if (ssid.length() > 13) ssid = ssid.substring(0, 12) + "~";

        char line[22];
        snprintf(line, sizeof(line), "%-13s c%d", ssid.c_str(), _wiphi_networks[idx].ch);
        wiphi_menuItem(y, sel, line);
    }

    if (visStart > 0)                        displayUI.display.drawString(122, 13, "^");
    if (visStart + 4 < _wiphi_networkCount)  displayUI.display.drawString(122, 52, "v");

    char cnt[8];
    snprintf(cnt, sizeof(cnt), "%d/%d", wiphi_apSel + 1, _wiphi_networkCount);
    displayUI.display.drawString(128 - (int)strlen(cnt) * 6 - 1, 55, cnt);

    displayUI.display.display();
}

void wiphi_drawAttackMenu() {
    displayUI.display.clear();
    wiphi_setFontSmall();
    wiphi_titleBar("Attack");

    char tgt[20];
    snprintf(tgt, sizeof(tgt), "->%.16s", _wiphi_selectedNetwork.ssid.c_str());
    displayUI.display.drawString(0, 13, tgt);

    for (int i = 0; i < WIPHI_ATK_ITEMS; i++) {
        wiphi_menuItem(24 + i * 10, i == wiphi_atkSel, WIPHI_ATK_LABELS[i]);
    }

    displayUI.display.display();
}

void wiphi_drawRunning() {
    displayUI.display.clear();
    wiphi_setFontSmall();
    wiphi_titleBar("Running");

    String mode;
    if (wiphi_deauthing_active && wiphi_hotspot_active) mode = "Deauth+EvilTwin";
    else if (wiphi_deauthing_active)                    mode = "Deauth Only";
    else if (wiphi_hotspot_active)                      mode = "EvilTwin Only";
    else                                                mode = "Idle";
    displayUI.display.drawString(0, 13, mode.c_str());

    char tgt[20];
    snprintf(tgt, sizeof(tgt), "->%.16s", _wiphi_selectedNetwork.ssid.c_str());
    displayUI.display.drawString(0, 24, tgt);

    char pkts[18];
    snprintf(pkts, sizeof(pkts), "Pkts: %lu", _wiphi_deauthCount);
    displayUI.display.drawString(0, 35, pkts);

    if (_wiphi_correct != "") {
        displayUI.display.drawString(0, 46, "!! PW CAPTURED !!");
    } else if (wiphi_hotspot_active) {
        char cli[20];
        snprintf(cli, sizeof(cli), "Clients: %d", WiFi.softAPgetStationNum());
        displayUI.display.drawString(0, 46, cli);
    }

    displayUI.display.display();
}

void wiphi_drawCaptured() {
    displayUI.display.clear();
    wiphi_setFontSmall();
    wiphi_titleBar("Captured!");

    if (_wiphi_correct == "") {
        displayUI.display.drawString(4, 18, "No password yet.");
        displayUI.display.drawString(4, 32, "Run Deauth+EvilTwin");
        displayUI.display.drawString(4, 46, "and wait.");
    } else {
        int sep = _wiphi_correct.lastIndexOf(": ");
        String pw = (sep >= 0) ? _wiphi_correct.substring(sep + 2) : _wiphi_correct;

        char net[22];
        snprintf(net, sizeof(net), "Net:%.14s", _wiphi_selectedNetwork.ssid.c_str());
        displayUI.display.drawString(0, 13, net);
        displayUI.display.drawLine(0, 24, 128, 24);
        displayUI.display.drawString(0, 26, "Password:");

        if (pw.length() > 14) {
            displayUI.display.drawString(4, 37, pw.substring(0, 14).c_str());
            displayUI.display.drawString(4, 49, pw.substring(14, 27).c_str());
        } else {
            displayUI.display.drawString(4, 37, pw.c_str());
        }
    }

    displayUI.display.display();
}

void wiphi_drawPwList() {
    displayUI.display.clear();
    wiphi_setFontSmall();
    wiphi_titleBar("Saved PWs");

    int count = 0;
    for (int i = 0; i < WIPHI_EE_SLOTS; i++) {
        SavedPW s = wiphi_eeReadSlot(i);
        int y     = 13 + i * 10;
        bool sel  = (i == wiphi_pwSel);

        char row[22];
        if (s.valid) {
            snprintf(row, sizeof(row), "%.14s", s.ssid);
            count++;
        } else {
            snprintf(row, sizeof(row), "(empty)");
        }
        wiphi_menuItem(y, sel, row);
    }

    if (count == 0) {
        displayUI.display.drawString(8, 32, "No saved passwords.");
    }

    displayUI.display.display();
}
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
void loop() {
    currentTime = millis();

    switch (appMode) {
        case AppMode::MAIN_MENU:      updateMainMenu();      break;
        case AppMode::NRF_MENU:       updateNrfMenu();       break;
        case AppMode::NRF_RUNNING:    updateNrfRunning();    break;
        case AppMode::DEAUTHER_SUITE: updateDeautherSuite(); break;
        case AppMode::WIPHI_APP:      updateWiPhiApp();      break;
    }
}

void updateButtons() {
    if (!displayUI.upBtn) return;

    displayUI.upBtn->update();
    displayUI.downBtn->update();
    displayUI.leftBtn->update();
    displayUI.rightBtn->update();
    displayUI.enterBtn->update();
    displayUI.backBtn->update();
}

void drawMainMenu() {
    displayUI.updatePrefix();
    displayUI.drawString(0, "Main Menu");

    for (int i = 0; i < MAIN_MENU_COUNT; i++) {
        String row = (i == mainSelected ? "> " : "  ");
        row += MAIN_MENU_ITEMS[i];
        displayUI.drawString(i + 1, row);
    }

    displayUI.updateSuffix();
}

void drawNrfBootScreen() {
    displayUI.updatePrefix();
    displayUI.drawString(0, "RF Hunter");
    displayUI.drawString(1, "NRF-Functions");
    displayUI.drawString(2, "Initializing...");
    displayUI.updateSuffix();
}

void drawNrfError() {
    displayUI.updatePrefix();
    displayUI.drawString(0, "RF Hunter");
    displayUI.drawString(1, "NRF Error!");
    displayUI.drawString(3, "BACK main menu");
    displayUI.updateSuffix();
}

void drawNrfMenu() {
    displayUI.updatePrefix();
    displayUI.drawString(0, "RF-Functions");
    displayUI.drawString(1, "Select Attack:");

    for (int i = 0; i < NRF_MODE_COUNT; i++) {
        String row = (i == nrfSelected ? "> " : "  ");
        row += NRF_MODES[i].label;
        displayUI.drawString(0, 24 + i * 12, row);
    }

    displayUI.updateSuffix();
}

void drawNrfRunning() {
    displayUI.updatePrefix();
    displayUI.drawString(0, "Running:");
    if (activeNrfMode >= 0) displayUI.drawString(1, NRF_MODES[activeNrfMode].label);
    displayUI.drawString(3, "BACK to stop");
    displayUI.drawString(4, "Hold BACK menu");
    displayUI.updateSuffix();
}

bool setupNrfRadio() {
    if (nrfReady) return true;

    drawNrfBootScreen();

    if (!radio.begin()) {
        Serial.println("[ERROR] NRF24 init failed!");
        drawNrfError();
        return false;
    }

    radio.setAutoAck(false);
    radio.stopListening();
    radio.setRetries(0, 0);
    radio.setPayloadSize(5);
    radio.setAddressWidth(3);
    radio.setPALevel(RF24_PA_MAX);
    radio.setDataRate(RF24_2MBPS);
    radio.setCRCLength(RF24_CRC_DISABLED);
    nrfReady = true;

    displayUI.drawString(70, 24, "OK");
    displayUI.updateSuffix();
    delay(800);

    return true;
}

void startCarrier() {
    if (!carrierActive) {
        radio.powerUp();
        delay(5);
        radio.startConstCarrier(RF24_PA_MAX, NRF_CARRIER_CH);
        carrierActive = true;
    }
}

void stopCarrier() {
    if (carrierActive) {
        radio.stopConstCarrier();
        carrierActive = false;
    }
}

void startNrfMode(int idx) {
    if ((idx < 0) || (idx >= NRF_MODE_COUNT)) return;

    activeNrfMode = idx;
    if (NRF_MODES[idx].needsCarrier) startCarrier();
    if (NRF_MODES[idx].init) NRF_MODES[idx].init();
    appMode = AppMode::NRF_RUNNING;
    drawNrfRunning();
}

void stopNrfMode() {
    stopCarrier();
    activeNrfMode = -1;
}

void startDeautherSuite() {
    if (!deautherStarted) {
        wifi::begin();
        wifi_set_promiscuous_rx_cb([](uint8_t* buf, uint16_t len) {
            scan.sniffer(buf, len);
        });

        names.load();
        ssids.load();
        cli.load();
        scan.setup();

        if (settings::getCLISettings().enabled) {
            cli.enable();
        } else {
            prntln(SETUP_SERIAL_WARNING);
        }

        if (settings::getWebSettings().enabled) wifi::startAP();

        deautherStarted = true;
        booted = true;
        EEPROMHelper::resetBootNum(BOOT_COUNTER_ADDR);
    }

    appMode = AppMode::DEAUTHER_SUITE;
    displayUI.mode = DISPLAY_MODE::INTRO;
}

void returnToMainMenu() {
    if (appMode == AppMode::NRF_RUNNING) stopNrfMode();

    if (appMode == AppMode::DEAUTHER_SUITE) {
        attack.stop();
        scan.stop();
    }

    if (appMode == AppMode::WIPHI_APP && wiphi_started) {
        stopWiPhiApp();
    }

    appMode = AppMode::MAIN_MENU;
    displayUI.mode = DISPLAY_MODE::OFF;
    mainSelected = 0;
    nrfSelected = 0;
    drawMainMenu();
}

void updateMainMenu() {
    updateButtons();
    if (!displayUI.upBtn) return;

    if (displayUI.upBtn->clicked()) {
        mainSelected = (mainSelected + MAIN_MENU_COUNT - 1) % MAIN_MENU_COUNT;
        drawMainMenu();
    } else if (displayUI.downBtn->clicked()) {
        mainSelected = (mainSelected + 1) % MAIN_MENU_COUNT;
        drawMainMenu();
    } else if (displayUI.enterBtn->clicked()) {
        if (mainSelected == 0) {
            if (setupNrfRadio()) {
                appMode = AppMode::NRF_MENU;
                nrfSelected = 0;
                drawNrfMenu();
            }
        } else if (mainSelected == 1) {
            startDeautherSuite();
        } else {
            startWiPhiApp();
        }
    }
}

void updateNrfMenu() {
    updateButtons();
    if (!displayUI.upBtn) return;

    if (displayUI.backHolding(5000)) {
        returnToMainMenu();
        return;
    }

    if (displayUI.upBtn->clicked()) {
        nrfSelected = (nrfSelected + NRF_MODE_COUNT - 1) % NRF_MODE_COUNT;
        drawNrfMenu();
    } else if (displayUI.downBtn->clicked()) {
        nrfSelected = (nrfSelected + 1) % NRF_MODE_COUNT;
        drawNrfMenu();
    } else if (displayUI.enterBtn->clicked()) {
        startNrfMode(nrfSelected);
    } else if (displayUI.backBtn->clicked()) {
        returnToMainMenu();
    }
}

void updateNrfRunning() {
    updateButtons();
    if (!displayUI.upBtn) return;

    if (displayUI.backHolding(5000)) {
        returnToMainMenu();
        return;
    }

    if (displayUI.backBtn->clicked()) {
        stopNrfMode();
        appMode = AppMode::NRF_MENU;
        nrfSelected = 0;
        drawNrfMenu();
        return;
    }

    if ((activeNrfMode >= 0) && NRF_MODES[activeNrfMode].tick) {
        NRF_MODES[activeNrfMode].tick();
    }

    static unsigned long lastDraw = 0;
    if (millis() - lastDraw > 1000UL) {
        drawNrfRunning();
        lastDraw = millis();
    }
}

void updateDeautherSuite() {
    wifi::update();
    attack.update();
    displayUI.update();
    cli.update();
    scan.update();
    ssids.update();

    if (displayUI.backHolding(5000)) {
        returnToMainMenu();
        return;
    }

    if (settings::getAutosaveSettings().enabled
        && (currentTime - autosaveTime > settings::getAutosaveSettings().time)) {
        autosaveTime = currentTime;
        names.save(false);
        ssids.save(false);
        settings::save(false);
    }
}

void nrfAttackAllInit() {}

void nrfAttackAllTick() {
    for (int ch = 0; ch < 125; ch++) radio.setChannel(ch);
}

void nrfAttackWiFiInit() {}

void nrfAttackWiFiTick() {
    for (int i = 0; i < numWifiCh; i++) radio.setChannel(wifiChannels[i]);
}

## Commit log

2026-05-26 Minor Bug fixed & Warning Added
    [RFHunter.ino]
2026-05-26 Hardware Source
    [0.96_OLED.kicad_pcb, 0.96_OLED.kicad_sch, D1_mini_LiPo_Shield.step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]

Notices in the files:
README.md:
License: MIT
